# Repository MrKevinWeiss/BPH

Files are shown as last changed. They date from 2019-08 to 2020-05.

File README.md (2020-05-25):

BPH (Bluepill Hat)
==================

## Description

The BPH is a hat for the Raspberry Pi 3 designed to connect
[PHiLIP-b](https://github.com/riot-appstore/PHiLIP) to a
DUT (Device Under Test) which typically consists of a micro-controller
development board.

It provides connections to communicate with PHiLIP, a convenient 20 pin ribbon
cable for the pinout to the DUT and some power control and monitoring. The
purpose is to make an easy to assembly and maintain setup for
HiL (hardware in the loop) testing at a low cost.

## Building the BPH

The BPH was designed so a skilled hobbiest can reproduce it.
The [gerber files](BPH-2C/PCB) and [BOM](BPH-2C/Assembly) for the PCB should be
enough to build a board.
[Board design files](https://workspace.circuitmaker.com/Projects/Details/Kevin-Weiss-2/bph) are also available.
Manufacturing costs for 100 board units range between 1000 to 2000 EUR for a turnkey solution.

Along with the BPH board, a [PHiLIP-b](https://github.com/riot-appstore/PHiLIP) is needed.

## Using the BPH

A [BPH interface](bph_pal/) is provided to make usage easier.

## Wiring

Using a standard ribbon cable to connect the BPH to the DUT the following wiring should be followed

BPH Pin | Color  | DUT Pin
--------|--------|----------
1       | BLACK  | DUT_NSS
2       | WHITE  | DUT_SCK
3       | GREY   | DUT_MISO
4       | PURPLE | DUT_MOSI
5       | BLUE   | DUT_IC
6       | GREEN  | DUT_SCL
7       | YELLOW | GND
8       | ORANGE | DUT_SDA
9       | RED    | DUT_RST
10      | BROWN  | DUT_PWM
11      | BLACK  | DUT_CTS
12      | WHITE  | DUT_DAC
13      | GREY   | DUT_RTS
14      | PURPLE | EXT_V_OUT
15      | BLUE   | DUT_RX
16      | GREEN  | DEBUG2
17      | YELLOW | DUT_TX
18      | ORANGE | DEBUG1
19      | RED    | DUT_ADC
20      | BROWN  | DEBUG0

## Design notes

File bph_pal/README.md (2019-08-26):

BPH PAL (Bluepill Hat Protocol Abstraction Layer)
================================

## Description

Provides both a simple shell interface, some useful CLI commands and a bootloader for the BPH.
Simplifies dealing with pinouts with a json config file.
Simplifies installation with a pip package.

### bph_pal installation
To install bph_pal use the python3 pip package.

`pip3 install bph_pal`

### Usage of bph_pal

To use the CLI calls check the help.

`python3 -m bph_pal -h`

For using the interactive shell, for example when testing.

`bph_shell`

For bootloading PHiLIP the port should be specified on the Raspberry Pi if another board is plugged in.

`bootload_philip -p /dev/ttyAMA0 -e -w -v -pv <PHiLIP_VERSION>`

The `-h` can also be used to see optional parameters.

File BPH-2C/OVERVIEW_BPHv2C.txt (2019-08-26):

Horizontal Dimension, max	68.7952mm
Vertical Dimension, max		70.0033mm
Total surface area		4617.8361sq.mm
Copper layer count		2
Smallest track width		0.0254mm
Smallest hole size		0.9400mm
Biggest hole size		2.5000mm
Number of plated through holes	130
Number of plated slots		0
Number of unplated holes	0
Number of unplated slots	0
Number of cutouts		2
Number of Unique Parts		14
Number of Components		29
Number of populated SMT Pads	74
Number of sides with components 1

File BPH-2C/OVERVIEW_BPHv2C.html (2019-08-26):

Altium

# Board Information

Date: | | 10/06/2019
Time: | | 16:36:54
Elapsed Time: | | 00:00:00
Filename: | | bph.CMPcbDoc
Units: | | mmmils

General
Horizontal Dimension, max | 68.7952mm
Vertical Dimension, max | 70.0033mm
Total surface area
Copper layer count | 2
Smallest electrical gap/space | -
Smallest track width | 0.0254mm
Smallest hole size | 0.94mm
Biggest hole size | 2.5mm
Number of plated through holes | 130
Number of plated slots | 0
Number of unplated holes | 0
Number of unplated slots | 0
Number of cutouts | 2

Back to top

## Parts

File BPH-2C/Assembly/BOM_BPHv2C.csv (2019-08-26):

Manufacturer | Manufacturer Part Number | Designator | Total Quantity | Description | Case | SMD/BGA/LCC/TH | Top/Bottom | Points | Total points | Comment | Unit Quantity | Number of boards | Digikey Part Number | Octopart URL | Supplier | SKU
Samsung Electro-Mechanics | CL10B105MO8NNWC | C1, C2, C5 | 300 | CL10 Series 0603 16 V 1 uF 20% Tolerance X7R Multilayer Ceramic Capacitor | 603 | SMD | Top | 2 | 6 | 1uF | 3 | 100 | 1276-6524-1-ND | http://octopart.com/cl10b105mo8nnwc-samsung-58699169 | DIGI-KEY | 1276-6524-1-ND
AVX Corporation | 06033C104KAT4A | C3, C4 | 300 | Multilayer Ceramic Capacitors MLCC - SMD/SMT 25volts 0.1uF 10% X7R | 603 | SMD | Top | 2 | 4 | 0.1uF | 2 | 100 | 478-7018-1-ND | https://octopart.com/06033c104kat4a-avx+interconnect+%2F+elco-8599646 | DIGI-KEY | 478-7018-1-ND
Toshiba Semiconductor and Storage | CUS10S30,H3F | D2, D3, D4, D5 | 400 | Diode Schottky 2-Pin SOD-323 | SOD323 | SMD | Top | 2 | 8 | Toshiba CUS10S30,H3F | 4 | 100 | CUS10S30H3FCT-ND | http://octopart.com/cus10s30%2Ch3f-toshiba-53632864 | DIGI-KEY | CUS10S30H3FCT-ND
Diodes Incorporated | DMP2035U-7 | Q1, Q3 | 200 | DMP2035U Series 20 V 35 mOhm P-Channel Enhancement Mode Mosfet - SOT-23-3 | SOT23 | SMD | Top | 3 | 6 | Diodes Inc. DMP2035U-7 | 2 | 100 | DMP2035U-7DICT-ND | http://octopart.com/dmp2035u-7-diodes+inc.-17747067 | DIGI-KEY | DMP2035U-7DICT-ND
Diodes Incorporated | DMN63D8L-7 | Q2, Q4 | 200 | Mosfet Bvdss: 25v~30v Sot23 t&r 3k | SOT23 | SMD | Top | 3 | 6 | Diodes Inc. DMN63D8L-7 | 2 | 100 | DMN63D8L-7DICT-ND | http://octopart.com/dmn63d8l-7-diodes+inc.-66661021 | DIGI-KEY | DMN63D8L-7DICT-ND
Panasonic Electronic Components | ERJ-3GEYJ222V | R1, R4, R5, R6, R7, R8, R9 | 700 | Thick Film Resistors - SMD 0603 2.2Kohms 5% Tol | 603 | SMD | Top | 2 | 14 | 2.2k | 7 | 100 | P2.2KGCT-ND | https://octopart.com/erj-3geyj222v-panasonic-55422038?r=sp&s=8AUfvkAbQV--CMs3oG4dvg | DIGI-KEY | P2.2KGCT-ND
Vishay Dale | CRCW1210220RFKEA | R10 | 100 | 220 Ohms ±1% 0.5W 1/2W Chip Resistor 1210 (3225 Metric) Automotive AEC-Q200 Thick Film | 1210 | SMD | Top | 2 | 2 | RES SMD 220 OHM 1% 1/2W 1210 | 1 | 100 | 541-220AACT-ND | https://octopart.com/crcw1210220rfkea-vishay-39812595?r=sp&s=OMXkOxqIT4yiYZ4NgJpWBw | DIGI-KEY | 541-220AACT-ND
Yageo | RL1210FR-070R1L | R11 | 100 | 100 mOhms ±1% 0.5W 1/2W Chip Resistor 1210 (3225 Metric) Automotive AEC-Q200 Current Sense Moisture Resistant Thick Film | 1210 | SMD | Top | 2 | 2 | RES 0.1 OHM 1% 1/2W 1210 | 1 | 100 | 311-0.1NACT-ND | https://octopart.com/rl1210fr-070r1l-yageo-20648606?r=sp&s=m9kaQ9GoQviQrXqUcR4W_g | DIGI-KEY | 311-0.1NACT-ND
Panasonic Electronic Components | ERJ-3GEYJ105V | R12, R13 | 200 | Thick Film Resistors - SMD 0603 1Mohms 5% Tol | 603 | SMD | Top | 2 | 4 | 1M | 2 | 100 | P1.0MGCT-ND | https://octopart.com/erj-3geyj105v-panasonic-55421976 | DIGI-KEY | P1.0MGCT-ND
Nidec Copal Electronics | CL-SB-12B-02T | S1 | 100 | Switch Slide N.O./N.C. SPDT Top Slide 0.2A 12VDC Gull Wing SMD T/R |  | SMD | Top | 3 | 3 | Nidec Copal CL-SB-12B-02T | 1 | 100 | 563-1319-1-ND | https://octopart.com/cl-sb-12b-02t-nidec+copal-85266657 | DIGI-KEY | 563-1319-1-ND
Texas Instruments | INA226AIDGST | U1 | 100 | 36-V, Bi-Directional, Ultra-High Accuracy, Low-/High-Side, I2C Out Current/Power Monitor w/ Alert 10-VSSOP -40 to 125 |  | SMD | Top | 10 | 10 | Texas Instruments INA226AIDGST | 1 | 100 | 296-29100-1-ND | https://octopart.com/ina226aidgst-texas+instruments-20304130?r=sp&s=5-Oqy-OESGqIFekITAPw-Q | DIGI-KEY | 296-29100-1-ND
Microchip Technology | MCP6001UT-I/OT | U2 | 100 | 1 MHz, Low-Power Operational Amplifier, 5-Pin SOT-23, Industrial Temperature, Tape and Reel | SOT23 | SMD | Top | 5 | 5 | MCP6001UT-I/OT | 1 | 100 | MCP6001UT-I/OTCT-ND | https://octopart.com/mcp6001ut-i%2Fot-microchip-419097 | DIGI-KEY | MCP6001UT-I/OTCT-ND
Yageo | RC0603JR-070RL | R14 | 100 | 0 Ohms Jumper 0.1W, 1/10W Chip Resistor 0603 (1608 Metric) Moisture Resistant Thick Film | 603 | SMD | Top | 2 | 2 | RES SMD 0 OHM JUMPER 1/10W 0603 | 1 | 100 | 311-0.0GRCT-ND | https://octopart.com/rc0603jr-070rl-yageo-1241539?r=sp&s=nHk_E6fcQS2Fz3BBMv6fyQ | DIGI-KEY | 311-0.0GRCT-ND
Vishay Semiconductor Opto Division | TLMG1100-GS08 | D1 | 100 | Green 570nm LED Indication - Discrete 2.1V 0603 (1608 Metric) | 603 | SMD | Top | 2 | 2 | LED GREEN 0603 SMD | 1 | 100 | 751-1165-1-ND | https://octopart.com/tlmg1100-gs08-vishay-42333640?r=sp&s=llalJoXeR1uhhDIWaEWUUQ | DIGI-KEY | 751-1165-1-ND

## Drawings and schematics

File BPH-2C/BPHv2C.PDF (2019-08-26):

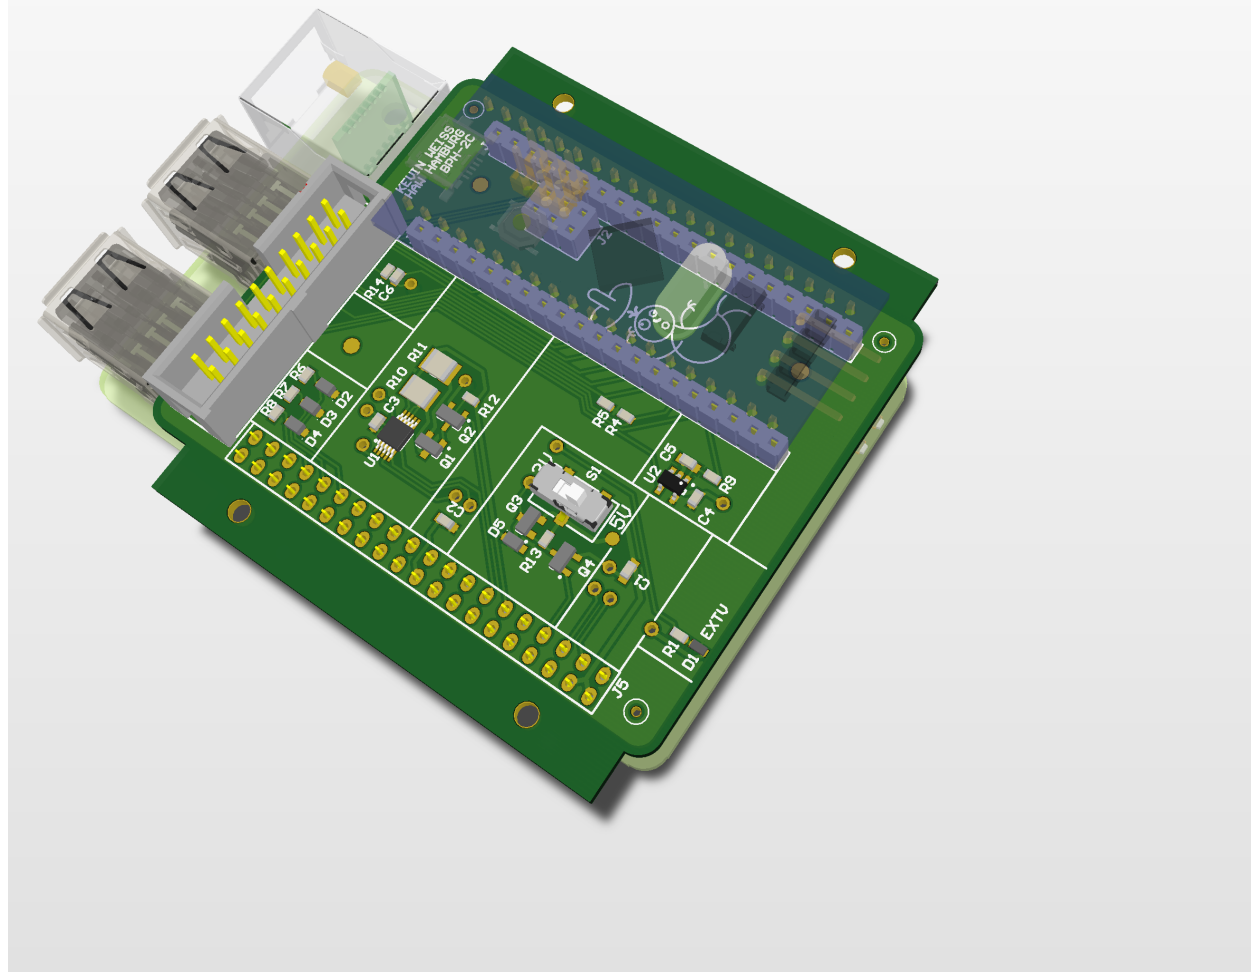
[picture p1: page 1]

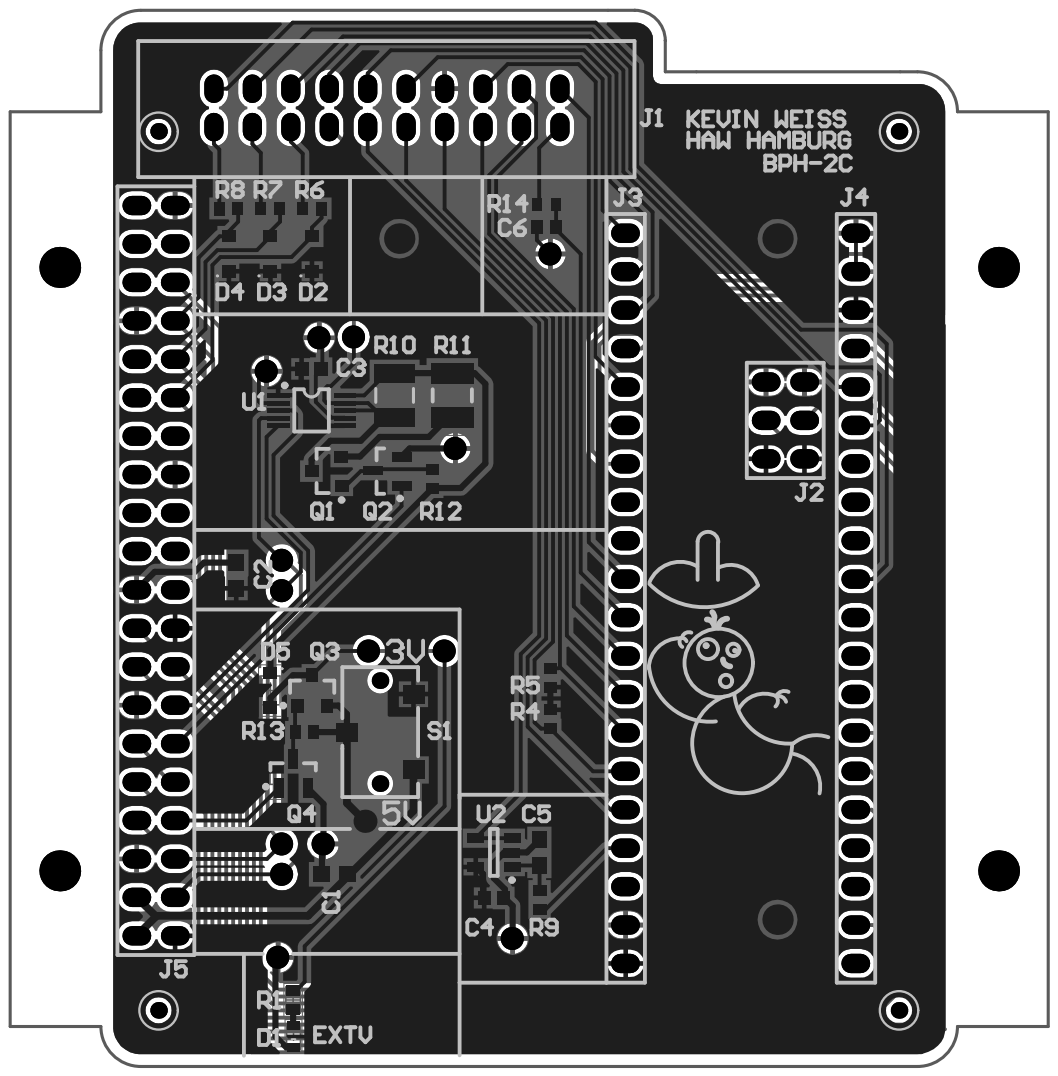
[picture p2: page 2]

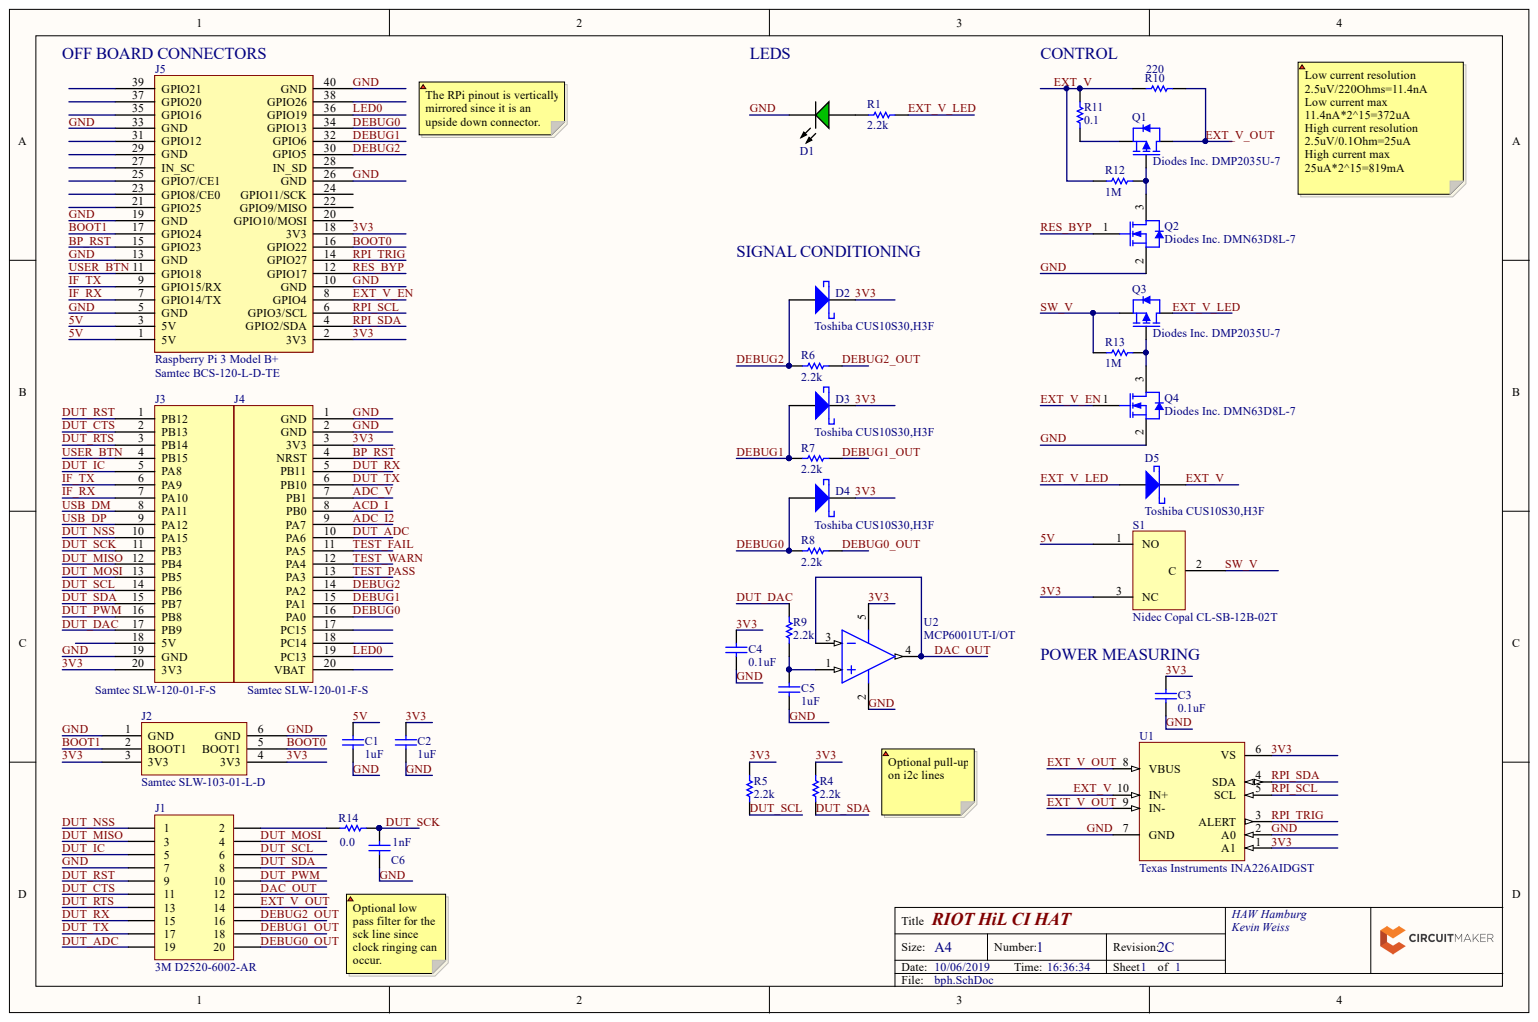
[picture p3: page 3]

RIOT HiL CI HA T T i t l e | HA W Ha m b u rg Kevi n Wei s s

A4 Size: | 1 N umber: | 2 C Rev i s i o n :
Date: 1 0 / 0 6 / 2 0 1 9 T ime: 1 6 : 3 6 : 3 4 | | Sheet 1 o f 1

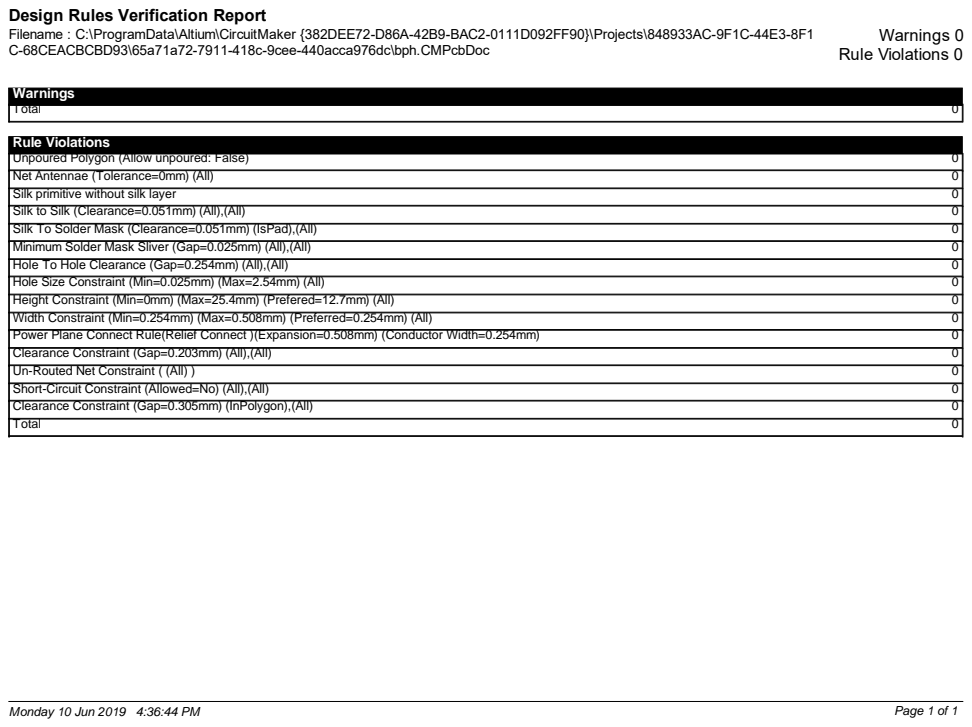
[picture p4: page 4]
Warnings 0 Rule Violations 0; Rule Violations; Unpoured Polygon (Allow unpoured: False); Net Antennae (Tolerance=0mm) (All); Silk primitive without silk layer; Silk to Silk (Clearance=0.051mm) (All),(All); Silk To Solder Mask (Clearance=0.051mm) (IsPad),(All); Minimum Solder Mask Sliver (Gap=0.025mm) (All),(All); Hole To Hole Clearance (Gap=0.254mm) (All),(All); Hole Size Constraint (Min=0.025mm) (Max=2.54mm) (All); Height Constraint (Min=0mm) (Max=25.4mm) (Prefered=12.7mm) (All)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

Design Rules Verification Report
Filename : C:\ProgramData\Altium\CircuitMaker {382DEE72-D86A-42B9-BAC2-0111D092FF90}\Projects\848933AC-9F1C-44E3-8F1
C-68CEACBCBD93\65a71a72-7911-418c-9cee-440acca976dc\bph.CMPcbDoc

# Electrical Rules Check Report

Class | Document | Message Successful Compile for bph.PrjPcb
Monday 10 Jun 2019 4:36:45 PM | Page 1 of 1

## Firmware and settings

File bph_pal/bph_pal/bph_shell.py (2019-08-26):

#! /usr/bin/env python3
# Copyright (c) 2019 Kevin Weiss, for HAW Hamburg  <kevin.weiss@haw-hamburg.de>
#
# This file is subject to the terms and conditions of the MIT License. See the
# file LICENSE in the top level directory for more details.
# SPDX-License-Identifier:    MIT

"""
This script handles interfacing to the BPH.  It handles the gpio, power
management/measurement.

The purpose of this script is allow easy setup and manual usage of the BPH.

Usage
-----

```
usage: bph_shell.py     [-h]
                        [--loglevel {debug,info,warning,error,fatal,critical}]
                        [--init_state]
                        [--pin_config_path]
                        [--pin_config_filename]

optional arguments:
  -h, --help            show this help message and exit
  --loglevel, -l {debug,info,warning,error,fatal,critical}
                        Python logger log level (default: warning)
  --init_state, -is
                        Initialized pins to default state on start
  --pin_config_path, -pp
                        Path to the board configuration file
  --pin_config_filename, -pf
                        Filename of the board config file
```
"""

import logging
import argparse
import time
import os
import glob
from json import decoder
from pprint import pprint
import subprocess
from cmd import Cmd
try:
    import readline
except ImportError:
    print("Cannot import readline, cannot use history")
    readline = None
try:
    from .driver_ina226 import INA226
except (ImportError, SystemError):
    try:
        from bph_pal.driver_ina226 import INA226
    except (ImportError, SystemError):
        from driver_ina226 import INA226
try:
    from .pin_control import PinControl
except (ImportError, SystemError):
    try:
        from bph_pal.pin_control import PinControl
    except (ImportError, SystemError):
        from pin_control import PinControl


class BphShell(Cmd):
    """Basic shell control for the Bluepill Hat for the Raspberry Pi 3"""
    prompt = "BPH: "

    def __init__(self, path=None, filename='bph_pinout_v2c.json',
                 init_state=False):
        self.pins = PinControl(path, filename, init_state)
        self.shunt = self.pins.pinout['shunt_res']
        self.gpio_map = self.pins.pinout['gpio']
        self.curmon = INA226(0x44, shunt_val=self.shunt['high_range']['val'])
        Cmd.__init__(self)

    def preloop(self):
        if readline:
            try:
                readline.read_history_file()
            except IOError:
                pass

    def do_load_pinmap(self, arg):
        """Loads and sets pinout states of BPH according to config file

        Usage:
            load_pinmap <path_to_config_file>

        Args:
            path_to_config_file: Path and filename of the config
                                 FileExistsError
        """
        try:
            self.pins.load_pinmap(arg, False)
            self.shunt = self.pins.pinout['shunt_res']
            self.gpio_map = self.pins.pinout['gpio']
        except (FileNotFoundError, decoder.JSONDecodeError) as exc:
            print(exc)

    @staticmethod
    def complete_load_pinmap(text, line, begidx, endidx):
        """Completes arg for path and filename"""
        text = text
        before_arg = line.rfind(" ", 0, begidx)
        if before_arg == -1:
            # arg not found
            return
        # fixed portion of the arg
        fixed = line[before_arg+1:begidx]
        arg = line[before_arg+1:endidx]
        pattern = arg + '*'

        completions = []
        for path in glob.glob(pattern):
            if path and os.path.isdir(path) and path[-1] != os.sep:
                path = path + os.sep
            completions.append(path.replace(fixed, "", 1))
        return completions

    def do_set_pin(self, arg):
        """Turns the pin high
        Usage:
            set_pin <pin_name>

        Args:
            pin_name: Pin name or key
        """
        try:
            self.pins.write_pin_state(arg, 1)
        except (ValueError, TypeError, KeyError) as exc:
            print(exc)

    def complete_set_pin(self, text, line, begidx, endidx):
        """Completes arg with possible pin names"""
        begidx = begidx
        endidx = endidx
        return self._show_pins(text, line)

    def do_clear_pin(self, arg):
        """Turns the pin low
        Usage:
            clear_pin <pin_name>

        Args:
            pin_name: Pin name or key
        """
        try:
            self.pins.write_pin_state(arg, 0)
        except (ValueError, TypeError, KeyError) as exc:
            print(exc)

    def complete_clear_pin(self, text, line, begidx, endidx):
        """Completes arg with possible pin names"""
        begidx = begidx
        endidx = endidx
        return self._show_pins(text, line)

    def do_input_pin(self, arg):
        """Turns the input for high impedance
        Usage:
            input_pin <pin_name>

        Args:
            pin_name: Pin name or key
        """
        try:
            self.pins.pin_to_input(arg)
        except (ValueError, TypeError, KeyError) as exc:
            print(exc)

    def complete_input_pin(self, text, line, begidx, endidx):
        """Completes arg with possible pin names"""
        begidx = begidx
        endidx = endidx
        return self._show_pins(text, line)

    def do_philip_reset(self, arg):
        """Provides a hard reset on PHiLIP board
        Usage:
            philip_reset
        """
        arg = arg
        self.do_clear_pin("BP_RST")
        time.sleep(0.3)
        self.do_input_pin("BP_RST")
        time.sleep(0.2)

    def do_power_source(self, arg):
        """Selects the power settings
        Usage:
            power_source <selection>

        Args:
            selection: The type of power mode to set
                       [external, none, all, usb]
        """
        if arg == "external":
            print("external power on, USB power off, PHiLIP on")
            self._set_usb(False)
            self.pins.pin_to_input("BP_RST")
            self.pins.write_pin_state("EXT_V_EN", 1)
        elif arg == "none":
            print("external power off, USB power off, PHiLIP off")
            self._set_usb(False)
            self.pins.write_pin_state("BP_RST", 0)
            self.pins.write_pin_state("EXT_V_EN", 0)
        elif arg == "all":
            print("external power on, USB power on, PHiLIP on")
            self._set_usb(True)
            self.pins.pin_to_input("BP_RST")
            self.pins.write_pin_state("EXT_V_EN", 1)
        elif arg == "usb":
            print("external power off, USB power on, PHiLIP on")
            self._set_usb(True)
            self.pins.pin_to_input("BP_RST")
            self.pins.write_pin_state("EXT_V_EN", 0)
        else:
            print("Invalid argument, no power change")

    @staticmethod
    def _set_usb(usb_on):
        subprocess.run("echo '1-1' | sudo tee /sys/bus/usb/drivers/usb/{} "
                       "> /dev/null".format("bind" if usb_on else "unbind"),
                       shell=True)

    @staticmethod
    def complete_power_source(text, line, begidx, endidx):
        """Completes arg with possible power source settings"""
        begidx = begidx
        endidx = endidx
        mline = line.partition(' ')[2]
        offs = len(mline) - len(text)
        power_opts = ['external', 'none', 'all', 'usb']
        return [s[offs:] for s in power_opts if s.startswith(mline)]

    def do_read_current(self, arg):
        """Reads current to the dut thorugh the ext voltage line
        Usage:
            read_current [range]

        Args:
            range: The range settings
                   [high_range<200mA, low_range<50uA]
        """
        func_args = (arg or '').split()
        try:
            if len(func_args) is 0:
                print("Current = {} A".format(self.curmon.get_current()))
            elif len(func_args) is 1:
                if func_args[0] == "high_range":
                    self.pins.write_pin_state("RES_BYP", 1)
                    self.curmon.set_shunt(self.shunt['high_range']['val'])
                elif func_args[0] == "low_range":
                    self.pins.write_pin_state("RES_BYP", 0)
                    self.curmon.set_shunt(self.shunt['low_range']['val'])
                else:
                    raise KeyError
                time.sleep(0.3)
                print("Current = {}A".format(self.curmon.get_current()))
        except KeyError as exc:
            print('Could not parse argument {}'.format(exc))
        except (TypeError, ValueError, SyntaxError) as exc:
            print(exc)

    @staticmethod
    def complete_read_current(text, line, begidx, endidx):
        """Completes arg with possible ranges"""
        begidx = begidx
        endidx = endidx
        mline = line.partition(' ')[2]
        offs = len(mline) - len(text)
        power_opts = ['high_range', 'low_range']
        return [s[offs:] for s in power_opts if s.startswith(mline)]

    def do_read_voltage(self, arg):
        """Reads voltage to the dut thorugh the ext voltage line
        Usage:
            read_current [voltage_type=bus]

        Args:
            voltage_type: The voltage types...
                          [bus, shunt]
        """
        func_args = (arg or '').split()
        try:
            if len(func_args) is 0:
                print("Bus = {} V".format(self.curmon.get_bus_voltage()))
            elif len(func_args) is 1:
                if func_args[0] == "bus":
                    print("Bus = {} V".format(self.curmon.get_bus_voltage()))
                elif func_args[0] == "shunt":
                    print("Shunt = {} V"
                          "".format(self.curmon.get_shunt_voltage()))
                else:
                    raise KeyError
        except KeyError as exc:
            print('Could not parse argument {}'.format(exc))
        except (TypeError, ValueError, SyntaxError) as exc:
            print(exc)

    @staticmethod
    def complete_read_voltage(text, line, begidx, endidx):
        """Completes arg with possible voltage types"""
        begidx = begidx
        endidx = endidx
        mline = line.partition(' ')[2]
        offs = len(mline) - len(text)
        power_opts = ['bus', 'shunt']
        return [s[offs:] for s in power_opts if s.startswith(mline)]

    @staticmethod
    def do_show_pinout(arg):
        """Prints the pinout for the connected board

        Usage:
            show_pinout
        """
        arg = arg
        print("""
[20]     - brown  - DEBUG0_OUT
    [19] - red    - DUT_ADC
[18]     - orange - DEBUG1_OUT
    [17] - yellow - DUT_TX
[16]     - green  - DEBUG2_OUT
    [15] - blue   - DUT_RX
[14]     - purple - EXT_V_OUT
    [13] - grey   - DUT_RTS
[12]     - white  - DAC_OUT
    [11] - black  - DUT_CTS
[10]     - brown  - DUT_PWM
    [ 9] - red    - DUT_RST
[ 8]     - orange - DUT_SDA
    [ 7] - yellow - GND
[ 6]     - green  - DUT_SCL
    [ 5] - blue   - DUT_IC
[ 4]     - purple - DUT_MOSI
    [ 3] - grey   - DUT_MISO
[ 2]     - white  - DUT_SCK
    [ 1] - black  - DUT_NSS
""")

    def do_pinmap(self, arg):
        """Shows the pinmap states and description
        Usage:
            pinmap
        """
        arg = arg
        pprint(sorted(self.gpio_map.items()))

    def _show_pins(self, text, line):
        mline = line.partition(' ')[2]
        offs = len(mline) - len(text)
        return [s[offs:] for s in self.gpio_map.keys() if s.startswith(mline)]

    @staticmethod
    def do_exit(arg):
        """I mean it should be obvious

        Usage:
            exit
        """
        arg = arg
        return True


def _exit_cmd_loop():
    if readline:
        try:
            readline.write_history_file()
        except IOError:
            pass


def main():
    """Main program"""
    parser = argparse.ArgumentParser()

    log_levels = ('debug', 'info', 'warning', 'error', 'fatal', 'critical')
    parser.add_argument('--loglevel', '-l', choices=log_levels, default='info',
                        help='Python logger log level')
    parser.add_argument('--pin_config_path', '-pp',
                        help="Path to the pin config",
                        default=None)
    parser.add_argument('--pin_config_filename', '-pf',
                        help="Filename of config",
                        default='bph_pinout_v2c.json')
    parser.add_argument('--init_state', '-is',
                        help='Initialize pins on startup',
                        default=False, action='store_true')
    pargs = parser.parse_args()

    logging.basicConfig(level=getattr(logging, pargs.loglevel.upper()))
    try:
        BphShell(pargs.pin_config_path,
                 pargs.pin_config_filename,
                 pargs.init_state).cmdloop()
        _exit_cmd_loop()
    except KeyboardInterrupt:

        _exit_cmd_loop()


if __name__ == '__main__':
    main()

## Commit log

2019-08-13 feature(bph_pal): Initial commit of bph_pal
    Add a rpi compatable bootloader for the bluepill
    Add bph_shell for interactive bph control
    Add bph_pal cli args for setup
    Add pip package info
    Update license
    Add ina226 driver
    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
2019-08-23 feat(BPH-2C): Add new design files
    This adds gerbers, bom and schematic of the BPH-2C version of the board
    This board has been tested and 100 units ordered from China
    [BOM_BPHv2C.csv, BOM_BPHv2C.xls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]
2019-08-23 feat(bph_pal): Major update and cleanup of bph_pal
    Add pin init function it the bph_pal CLI
    Fix bootloader to only open binary file if needed
    Add bootloader fetch binary from github release
    Add bootloader pins from config file
    Update setup.py file with new requirements and release number
    [__main__.py, bph_shell.py, stm32uartboot.py]
2020-05-25 README: Add wiring colors
